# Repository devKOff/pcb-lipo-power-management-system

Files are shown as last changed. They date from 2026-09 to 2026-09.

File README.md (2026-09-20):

<div align="center">

# Project 2 — Power Management System

**A compact, integrated PCB for Li-Po battery charging, protection, and switch-selectable 5 V / 12 V output.**

Combines a TP4056 Li-Po charging stage, DW01A/FS8205A battery protection, and an MT3608 boost
converter on a single two-layer board — designed for portable electronics, IoT nodes,
Arduino-based projects, and lightweight UAV subsystems.






</div>

---

## Table of Contents

- [Overview](#overview)
- [3D Board Renders](#3d-board-renders)
- [Schematic](#schematic)
- [PCB Layer Breakdown](#pcb-layer-breakdown)
- [Bill of Materials & Manufacturing Files](#bill-of-materials--manufacturing-files)
- [Repository Structure](#repository-structure)
- [Getting Started](#getting-started)
- [License](#license)

---

## Overview

| | |
|---|---|
| **Board name** | Project 2 — Power Management System |
| **Function** | Li-Po charging + protection + selectable 5 V/12 V boost output |
| **Charging IC** | TP4056 (USB Type-C input, CC/CV charging) |
| **Protection ICs** | DW01A + FS8205A (overcharge / over-discharge / overcurrent) |
| **Boost converter** | MT3608 (switch-selectable ≈5 V / ≈12 V output) |
| **Layers** | 2-layer PCB |
| **EDA tool** | KiCad v10 |

---

## 3D Board Renders

<div align="center">

<table>
  <tr>
    <td align="center"><strong>Isometric View</strong></td>
    <td align="center"><strong>Top View</strong></td>
    <td align="center"><strong>Bottom View</strong></td>
  </tr>
  <tr>
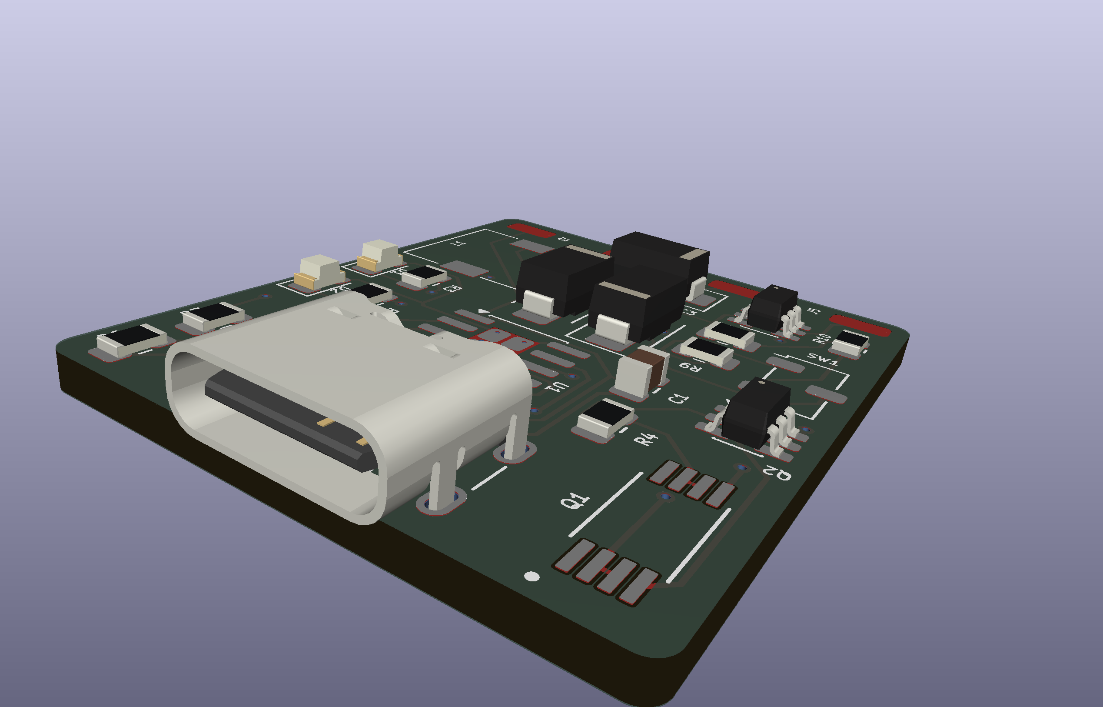
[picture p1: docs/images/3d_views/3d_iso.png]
Isometric 3D render of the PCB
    <td></td>
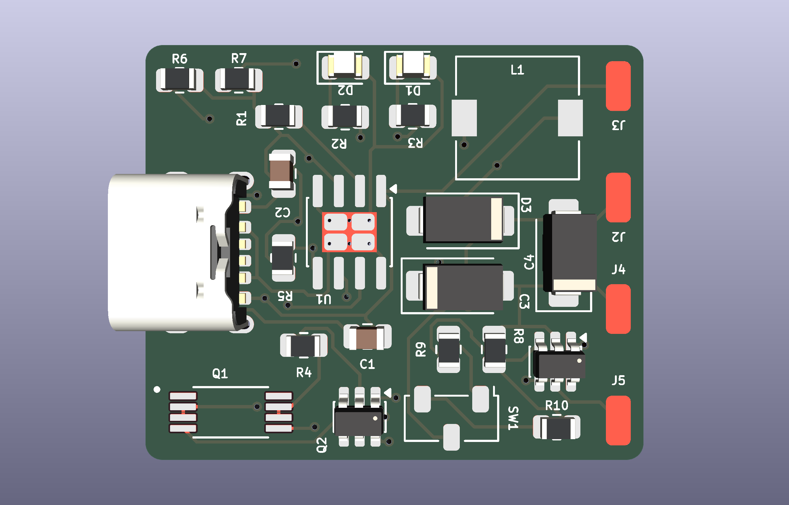
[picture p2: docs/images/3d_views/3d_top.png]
Top 3D render of the PCB
    <td></td>
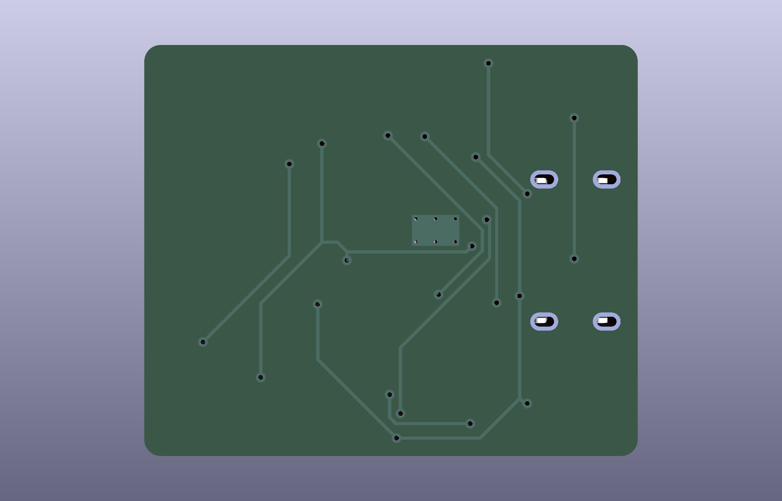
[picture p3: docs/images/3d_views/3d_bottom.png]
Bottom 3D render of the PCB
    <td></td>
  </tr>
</table>

</div>

---

## Schematic

Full schematic of the charging, protection, and boost-conversion circuitry:

<div align="center">
  Project 2 full schematic
</div>

> If the vector render above does not display (GitHub occasionally sandboxes inline SVG),
> open it directly: [`docs/images/schematics/project2.svg`](docs/images/schematics/project2.svg).
> A PNG fallback may also be available at `docs/images/schematics/project2.png`.

---

## PCB Layer Breakdown

### Primary Layers

**Top Copper (F.Cu)** | **Bottom Copper (B.Cu)**
:---:|:---:
Top Copper | Bottom Copper

**Top Silkscreen (F.Silkscreen)** | **Bottom Silkscreen (B.Silkscreen)**
:---:|:---:
Top Silkscreen | Bottom Silkscreen

**Board Outline (Edge.Cuts)**
:---:
Edge Cuts

### Supplementary Layers

<details>
<summary><strong>All-Layers Overlay</strong> (click to expand)</summary>
<br>

All Layers Overlay

</details>

<details>
<summary><strong>Solder Mask Layers — Top (F.Mask) &amp; Bottom (B.Mask)</strong> (click to expand)</summary>
<br>

**Top Solder Mask (F.Mask)** | **Bottom Solder Mask (B.Mask)**
:---:|:---:
Top Solder Mask | Bottom Solder Mask

</details>

---

## Bill of Materials & Manufacturing Files

| Deliverable | Description | Link |
|---|---|---|
| 📋 Bill of Materials | Full component list with references, values, and quantities | [`docs/power_management_system_bom.csv`](docs/power_management_system_bom.csv) |
| 🏭 Gerber Files | Fabrication-ready Gerber package for PCB manufacturing | [`gerbers/`](gerbers/) |
| 🧩 STEP 3D CAD File | Mechanical 3D model for enclosure/assembly integration | [`step/`](step/) |
| 🗂️ KiCad Project | Top-level KiCad project file | [`project2.kicad_pro`](project2.kicad_pro) |
| 🔲 KiCad PCB Layout | Editable PCB layout file | [`project2.kicad_pcb`](project2.kicad_pcb) |
| ⚡ KiCad Schematic | Editable schematic source file | [`project2.kicad_sch`](project2.kicad_sch) |

> **Note:** If the BOM is provided as a spreadsheet instead of CSV, use
> [`docs/power_management_system_bom.xlsx`](docs/power_management_system_bom.xlsx).

---

## Repository Structure

```text
pcb-lipo-power-management-system/
├── docs/
│   ├── images/
│   │   ├── 3d_views/
│   │   │   ├── 3d_top.png
│   │   │   ├── 3d_iso.png
│   │   │   └── 3d_bottom.png
│   │   ├── schematics/
│   │   │   └── project2.svg
│   │   └── pcb_layers/
│   │       ├── pcb_All_layers.svg
│   │       ├── project2-F_Cu.svg
│   │       ├── project2-B_Cu.svg
│   │       ├── project2-F_Silkscreen.svg
│   │       ├── project2-B_Silkscreen.svg
│   │       ├── project2-F_Mask.svg
│   │       ├── project2-B_Mask.svg
│   │       └── project2-Edge_Cuts.svg
│   └── power_management_system_bom.csv
├── gerbers/
│   └── (fabrication Gerber + drill files)
├── step/
│   └── (STEP 3D CAD export)
├── assets/
│   └── datasheets/
│       └── (component datasheets: TP4056, MT3608, DW01A, FS8205A, etc.)
├── .history/
│   └── (local edit history / backups, excluded from releases)
├── .gitignore
├── DRC.rpt
├── report.txt
├── project2.kicad_pro
├── project2.kicad_pcb
├── project2.kicad_prl
├── project2.kicad_sch
├── LICENSE
└── README.md
```

> **Note:** `.history/`, `DRC.rpt`, `report.txt`, and `temp-freerouting.dsn` are local
> KiCad/tooling artifacts. Consider adding them to `.gitignore` if they don't need to be
> version-controlled — they're listed here only for completeness.

---

## Getting Started

1. **Clone the repository**
   ```bash
   git clone https://github.com/devKOff/pcb-lipo-power-management-system.git
   cd pcb-lipo-power-management-system
   ```
2. **Open in KiCad v10**
   Open [`project2.kicad_pro`](project2.kicad_pro) in KiCad to view or edit the schematic and PCB layout.
3. **Manufacture the board**
   Send the contents of [`gerbers/`](gerbers/) directly to your PCB fabricator, and reference
   [`docs/power_management_system_bom.csv`](docs/power_management_system_bom.csv) for assembly.
4. **Mechanical integration**
   Import the STEP file from [`step/`](step/) into your CAD tool of choice for enclosure or
   assembly design.

---

## License

This project is released under the terms of the [MIT License](LICENSE). Hardware design files
are shared in the spirit of open source hardware — see the OSHW badge above.

> **Note:** No `LICENSE` file currently exists in this repository. Add one (e.g. via GitHub's
> *Add file → Create new file → LICENSE* flow, which offers an MIT template) so the badge and
> link above resolve correctly — see Step 6 in the upload guide below.

<div align="center">

*Maintained as part of the Project 2 — Power Management System hardware design effort.*

</div>

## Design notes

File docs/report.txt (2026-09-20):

Plotted to 'E:\GIT\PCB\project1\project2\docs\project2.ps'.
Info: Done.

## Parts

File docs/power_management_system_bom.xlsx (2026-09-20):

Bill of Materials (BOM) — Power Management System
Project: Integrated PCB Li-Po Charger & Selectable 5V/12V Boost Module | Sheet: 1/1
Item # | Ref Des | Qty | Value / Part | Category / Function | KiCad Symbol Library | Footprint / Package | Part Number / LCSC Ref | Description
Active Integrated Circuits & Semiconductors
1 | U1 | 1 | TP4056-42-ESOP8 | Power Management IC | Power_Management | Package_SO:SOP-8-PP_3.9x4.9mm_P1.27mm | TP4056 / C16581 | 1A Standalone Linear Li-Ion Battery Charger
2 | U2 | 1 | MT3608 | DC-DC Boost Converter | Power_Switching | Package_TO_SOT_SMD:SOT-23-6 | MT3608 / C84817 | 1.2MHz, 2A High-Efficiency Step-Up Converter
3 | U3 | 1 | DW01A | Battery Protection IC | Battery_Management | Package_TO_SOT_SMD:SOT-23-6 | DW01A / C14211 | One-Cell Li-Ion/Li-Po Battery Protection Controller
4 | Q1 | 1 | FS8205A | Protection MOSFET | Transistor_FET | Package_SO:TSSOP-8_4.4x3mm_P0.65mm | FS8205A / C16130 | Dual N-Channel Common-Drain MOSFET Switch
5 | D3 | 1 | SS34 | Schottky Diode | Diode | Diode_SMD:D_SMA | SS34 / C1591 | 3A / 40V Surface Mount Schottky Barrier Diode
6 | D1, D2 | 2 | LED (Red/Green) | Status Indicators | Device | LED_SMD:LED_0805_2012Metric | Generic 0805 LED | Surface Mount Status Indicators (CHRG / STDBY)
Resistors (SMD 0805)
7 | R1 | 1 | 1.2kΩ | Resistor | Device | Resistor_SMD:R_0805_2012Metric | 0805W8F1201T5E | Sets TP4056 charge current to 1A (PROG)
8 | R2, R3 | 2 | 1kΩ | Resistor | Device | Resistor_SMD:R_0805_2012Metric | 0805W8F1001T5E | LED Current Limiting Resistors
9 | R4 | 1 | 1kΩ | Resistor | Device | Resistor_SMD:R_0805_2012Metric | 0805W8F1001T5E | DW01A Overcurrent Current-Sense Resistor
10 | R5 | 1 | 100Ω | Resistor | Device | Resistor_SMD:R_0805_2012Metric | 0805W8F1000T5E | DW01A VCC Filtering Resistor
11 | R6, R7 | 2 | 5.1kΩ | Resistor | Device | Resistor_SMD:R_0805_2012Metric | 0805W8F5101T5E | USB Type-C CC1/CC2 Pull-down Resistors
12 | R8 | 1 | 2.2kΩ | Resistor | Device | Resistor_SMD:R_0805_2012Metric | 0805W8F2201T5E | MT3608 Feedback Divider Ground Resistor
13 | R9 | 1 | 42kΩ | Resistor | Device | Resistor_SMD:R_0805_2012Metric | 0805W8F4202T5E | MT3608 Feedback Resistor (Selects ~12V Output)
14 | R10 | 1 | 16kΩ | Resistor | Device | Resistor_SMD:R_0805_2012Metric | 0805W8F1602T5E | MT3608 Feedback Resistor (Selects ~5V Output)
Capacitors & Power Passives
15 | C1 | 1 | 10uF | Ceramic Capacitor | Device | Capacitor_SMD:C_0805_2012Metric | CL21A106KOQNNNE | TP4056 Input/Output Decoupling Capacitor
16 | C2 | 1 | 100nF | Ceramic Capacitor | Device | Capacitor_SMD:C_0603_1608Metric | CL10B104KO8NNNC | DW01A VCC Power Decoupling Capacitor
17 | C3, C4 | 2 | 10uF | Ceramic Capacitor | Device | Capacitor_SMD:C_0805_2012Metric | CL21A106KOQNNNE | MT3608 Input & Output Filter Capacitors
18 | L1 | 1 | 22uH | Power Inductor | Device | Inductor_SMD:L_7.3x7.3_H4.5 | CDRH74T-220MC / C16822 | 22µH Shielded Power Inductor (Boost Converter)
Connectors & Switches
19 | J1 | 1 | USB_C_6P | USB Receptacle | Connector | Connector_USB:USB_C_Receptacle_6P | TYPE-C-31-M-12 / C165948 | USB Type-C 6-Pin Power Input Jack
20 | SW1 | 1 | SW_SPDT | Slide Switch | Switch | Button_Switch_SMD:SW_SPDT_PCM12 | CAS-120A1 / SK-12D07 | SPDT Switch for 5V / 12V Voltage Rail Selection
21 | J2, J3 | 2 | 1-Pin Header | Output Terminal | Connector | Connector_PinHeader_2.54mm:1x01 | Generic 2.54mm Header | System Output Pins (OUT+, OUT-)
22 | J4, J5 | 2 | 1-Pin Header | Battery Terminal | Connector | Connector_PinHeader_2.54mm:1x01 | Generic 2.54mm Header | Li-Po Battery Connector Pins (BAT+, BAT-)
Total Components:

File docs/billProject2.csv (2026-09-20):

Reference | Qty | Value | DNP | Exclude from BOM | Exclude from Board | Exclude from Simulation | Exclude from Position Files | Footprint | Datasheet
C1 | 1 | 10uF |  |  |  |  | ${EXCLUDE_FROM_POS_FILES} | Capacitor_SMD:C_0805_2012Metric
C2 | 1 | 100nF |  |  |  |  | ${EXCLUDE_FROM_POS_FILES} | Capacitor_SMD:C_0805_2012Metric
C3,C4 | 2 | C |  |  |  |  | ${EXCLUDE_FROM_POS_FILES} | Diode_SMD:D_SMA
D1,D2 | 2 | LED |  |  |  |  | ${EXCLUDE_FROM_POS_FILES} | LED_SMD:LED_0805_2012Metric
D3 | 1 | SS34 |  |  |  |  | ${EXCLUDE_FROM_POS_FILES} | Diode_SMD:D_SMA | https://www.vishay.com/docs/88751/ss32.pdf
J1 | 1 | USB_C_Receptacle_PowerOnly_6P |  |  |  |  | ${EXCLUDE_FROM_POS_FILES} | Connector_USB:USB_C_Receptacle_GCT_USB4125-xx-x_6P_TopMnt_Horizontal | https://www.usb.org/sites/default/files/documents/usb_type-c.zip
J2,J3,J4,J5 | 4 | Conn_01x01_Socket |  |  |  |  | ${EXCLUDE_FROM_POS_FILES} | Connector_Wire:SolderWirePad_1x01_SMD_1.5x3mm
L1 | 1 | 22uH |  |  |  |  | ${EXCLUDE_FROM_POS_FILES} | Inductor_SMD:L_7.3x7.3_H4.5
Q1 | 1 | FS8205A |  |  |  |  | ${EXCLUDE_FROM_POS_FILES} | FS8205A:SOP65P640X120-8N
Q2 | 1 | DW01A |  |  |  |  | ${EXCLUDE_FROM_POS_FILES} | Package_TO_SOT_SMD:SOT-23-6
R1 | 1 | 1.2k |  |  |  |  | ${EXCLUDE_FROM_POS_FILES} | Resistor_SMD:R_0805_2012Metric
R2,R3,R4 | 3 | 1k |  |  |  |  | ${EXCLUDE_FROM_POS_FILES} | Resistor_SMD:R_0805_2012Metric
R5 | 1 | 100 |  |  |  |  | ${EXCLUDE_FROM_POS_FILES} | Resistor_SMD:R_0805_2012Metric
R6,R7 | 2 | 5.1k |  |  |  |  | ${EXCLUDE_FROM_POS_FILES} | Resistor_SMD:R_0805_2012Metric
R8 | 1 | 2.2k |  |  |  |  | ${EXCLUDE_FROM_POS_FILES} | Resistor_SMD:R_0805_2012Metric
R9 | 1 | 42k |  |  |  |  | ${EXCLUDE_FROM_POS_FILES} | Resistor_SMD:R_0805_2012Metric
R10 | 1 | 16k |  |  |  |  | ${EXCLUDE_FROM_POS_FILES} | Resistor_SMD:R_0805_2012Metric
SW1 | 1 | SW_Nidec_CAS-120A1 |  |  |  |  | ${EXCLUDE_FROM_POS_FILES} | Button_Switch_SMD:Nidec_Copal_CAS-120A | https://www.nidec-components.com/e/catalog/switch/cas.pdf
U1 | 1 | TP4056-42-ESOP8 |  |  |  |  | ${EXCLUDE_FROM_POS_FILES} | Package_SO:SOIC-8-1EP_3.9x4.9mm_P1.27mm_EP2.41x3.3mm_ThermalVias | https://www.lcsc.com/datasheet/lcsc_datasheet_2410121619_TOPPOWER-Nanjing-Extension-Microelectronics-TP4056-42-ESOP8_C16581.pdf
U2 | 1 | MT3608 |  |  |  |  | ${EXCLUDE_FROM_POS_FILES} | Package_TO_SOT_SMD:SOT-23-6 | https://www.olimex.com/Products/Breadboarding/BB-PWR-3608/resources/MT3608.pdf

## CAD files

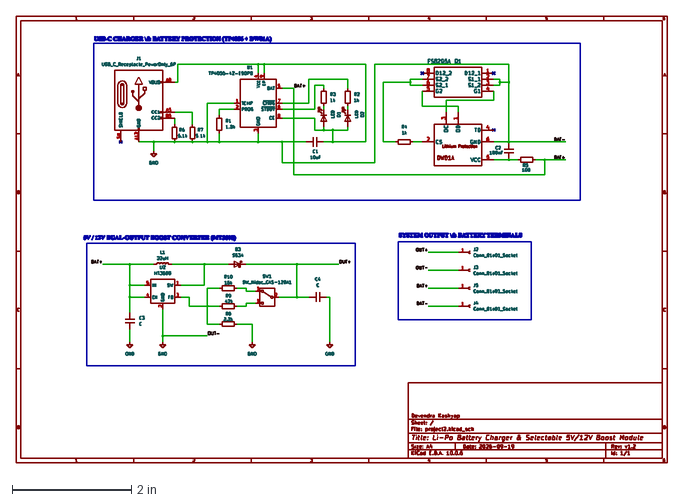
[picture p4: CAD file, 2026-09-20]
docs/project2.dxf
10.9 x 7.48 in

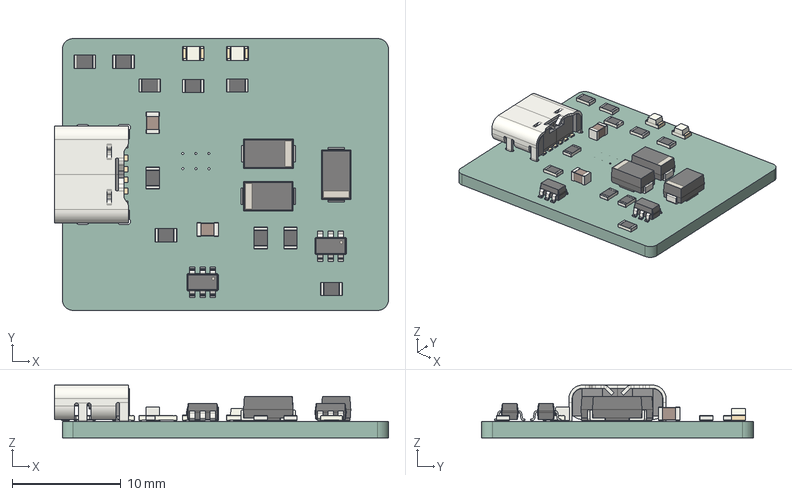
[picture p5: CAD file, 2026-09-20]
step/project2.step
30.7 x 25.0 x 4.85 mm
R_0805_2012Metric x 10
D_SMA x 3
C_0805_2012Metric x 2
SOT-23-6 x 2
LED_0805_2012Metric x 2
USB_C_Receptacle_GCT_USB4125-xx-x_6P_TopMnt_Horizontal
pro2E28_PCB

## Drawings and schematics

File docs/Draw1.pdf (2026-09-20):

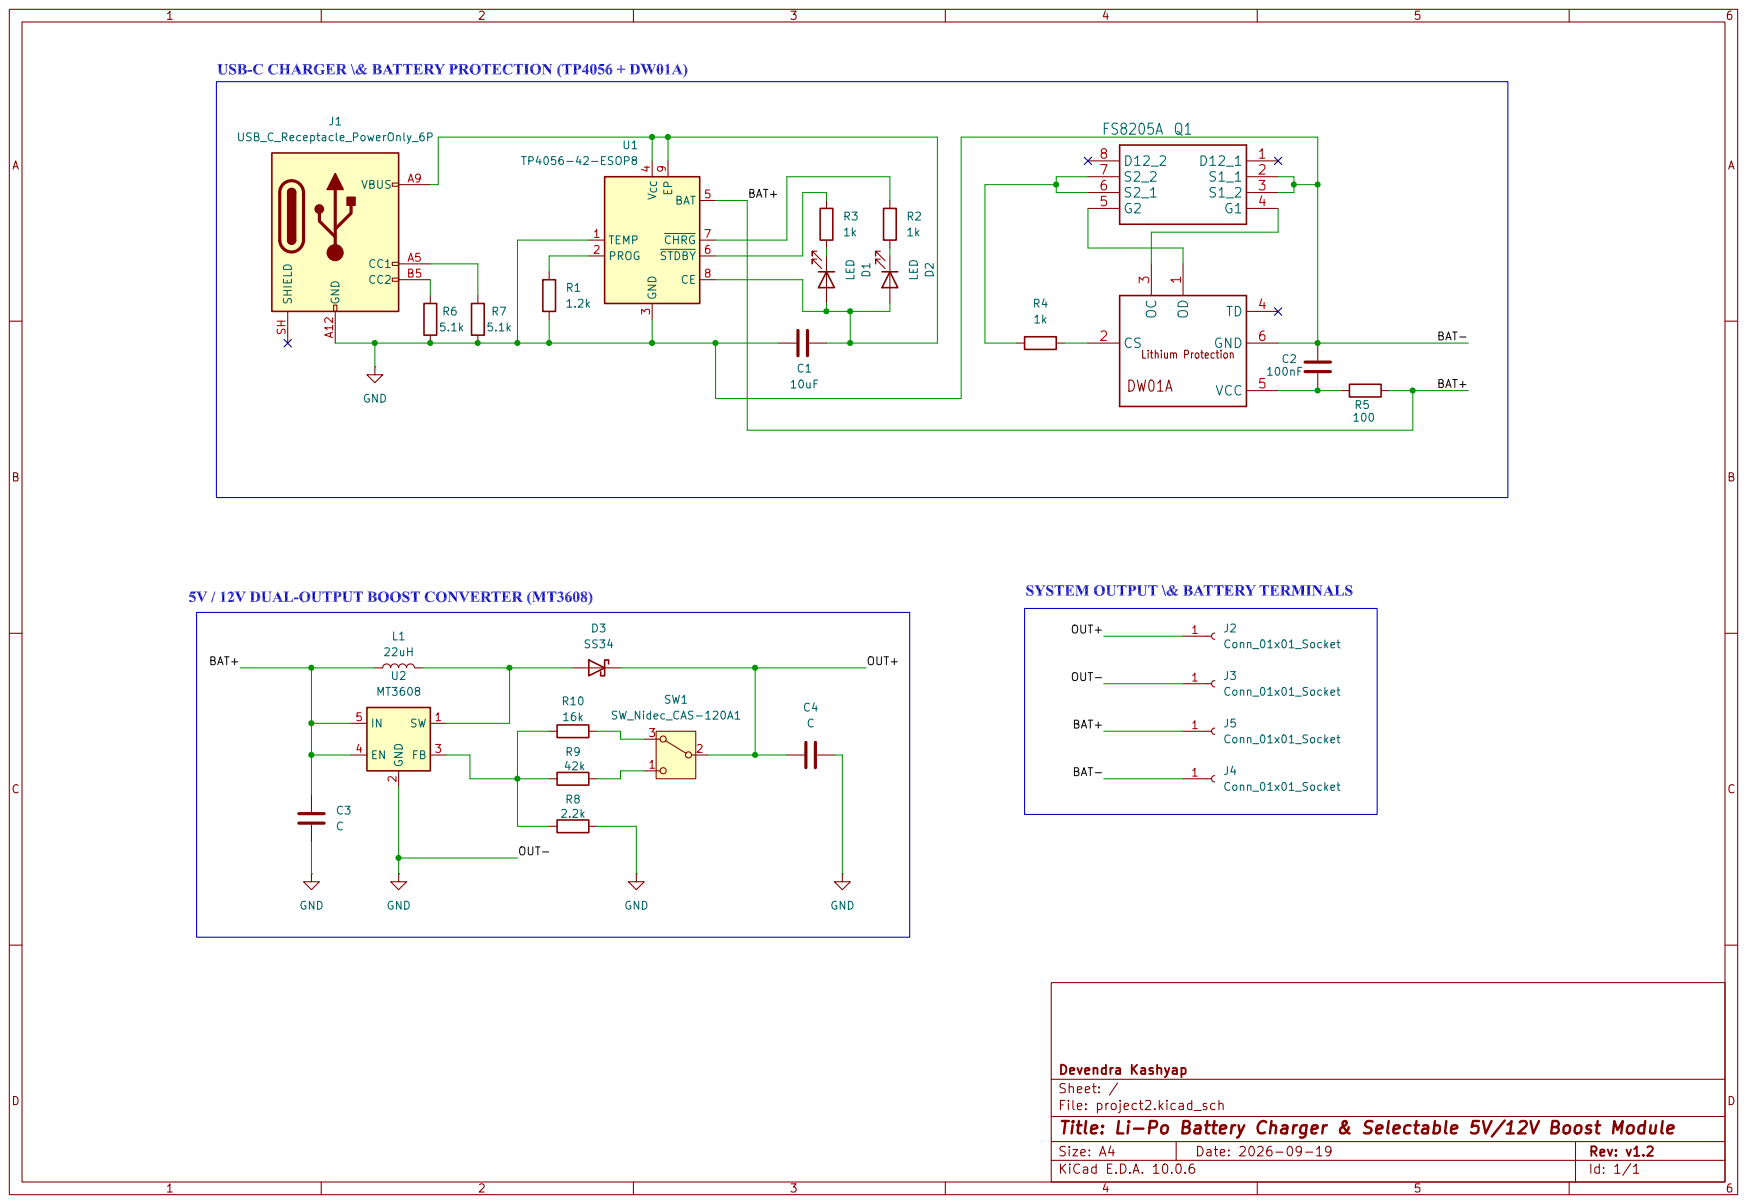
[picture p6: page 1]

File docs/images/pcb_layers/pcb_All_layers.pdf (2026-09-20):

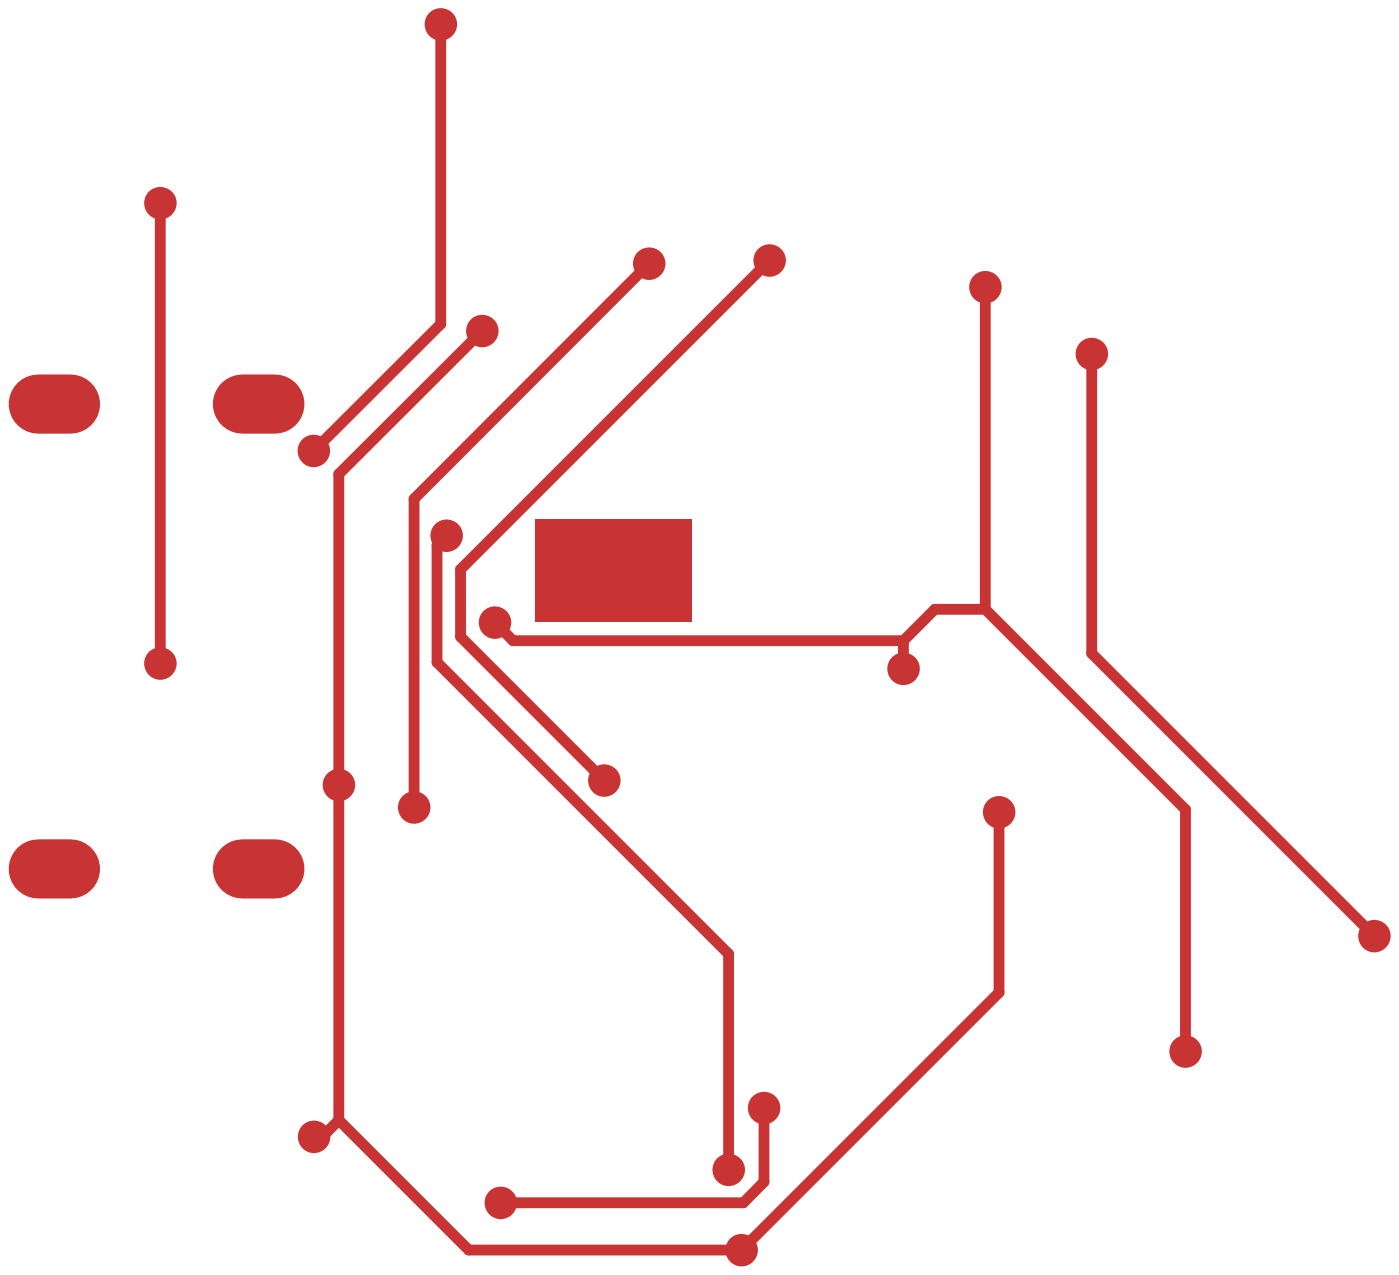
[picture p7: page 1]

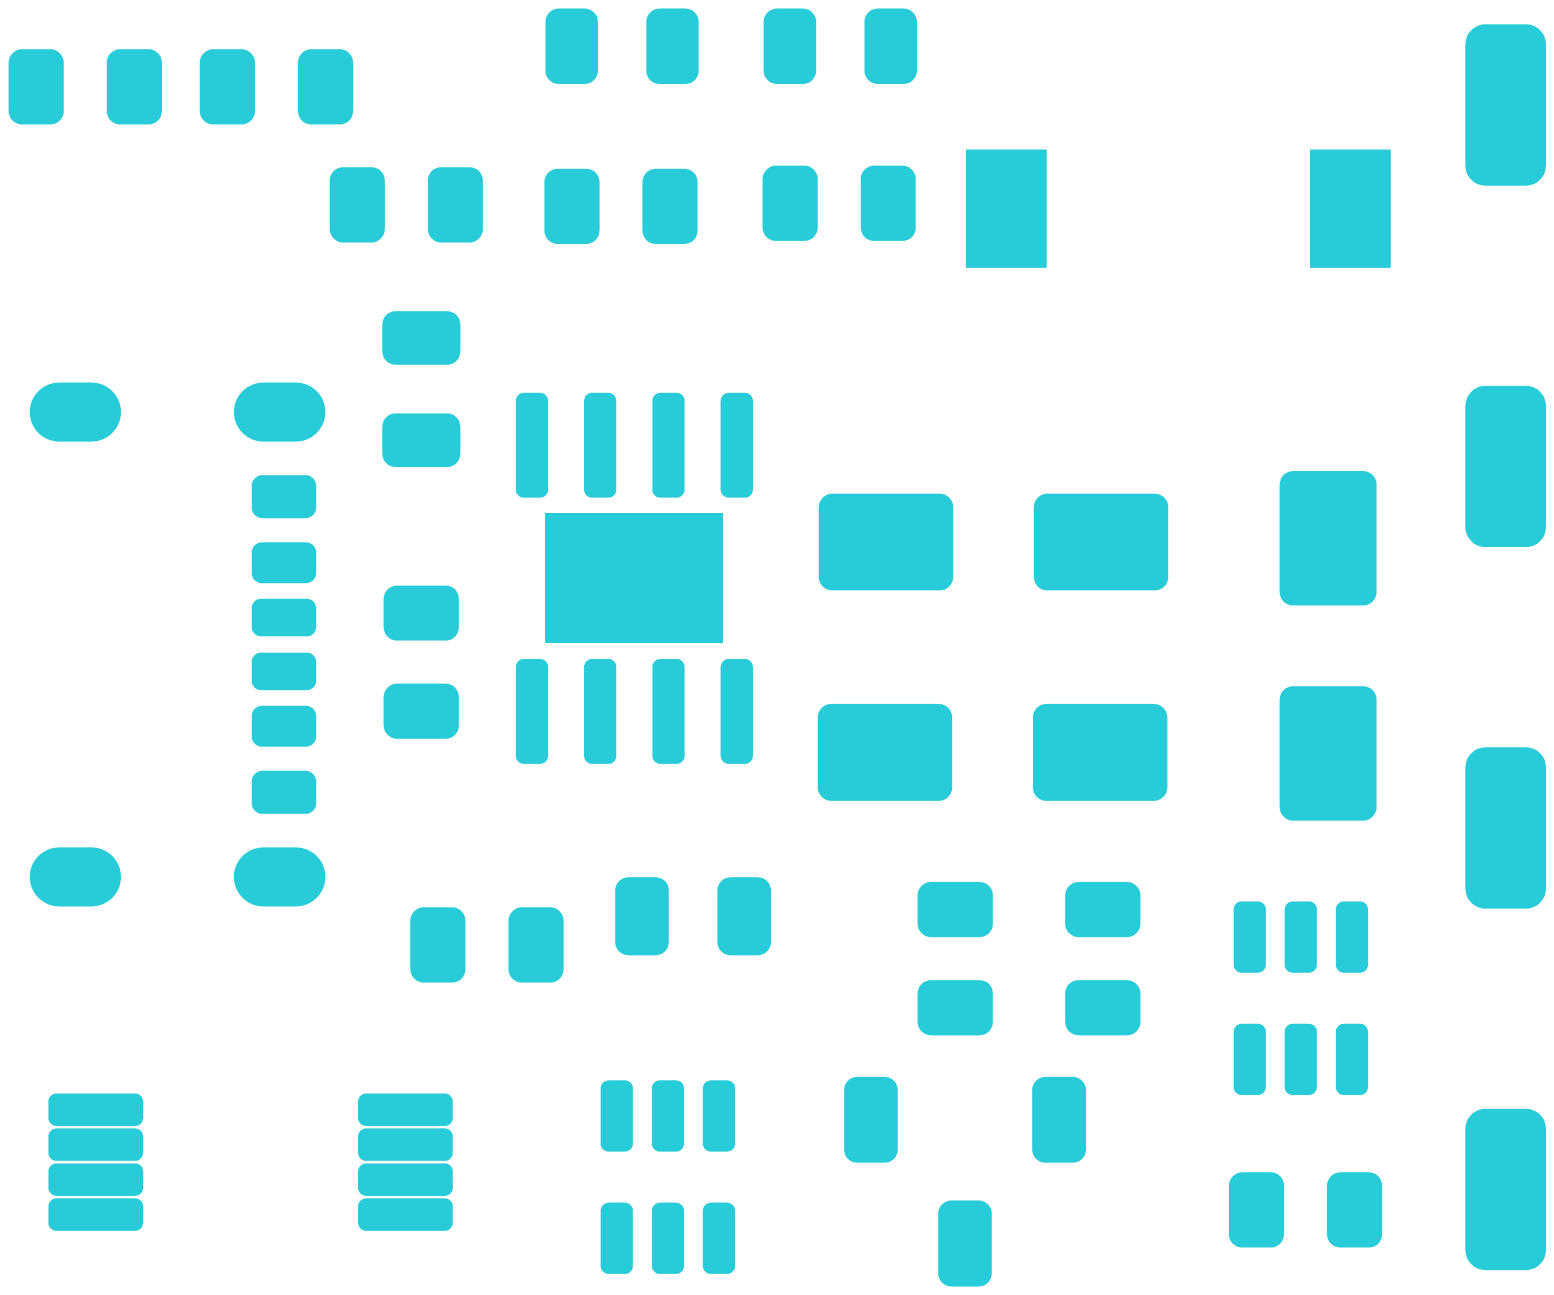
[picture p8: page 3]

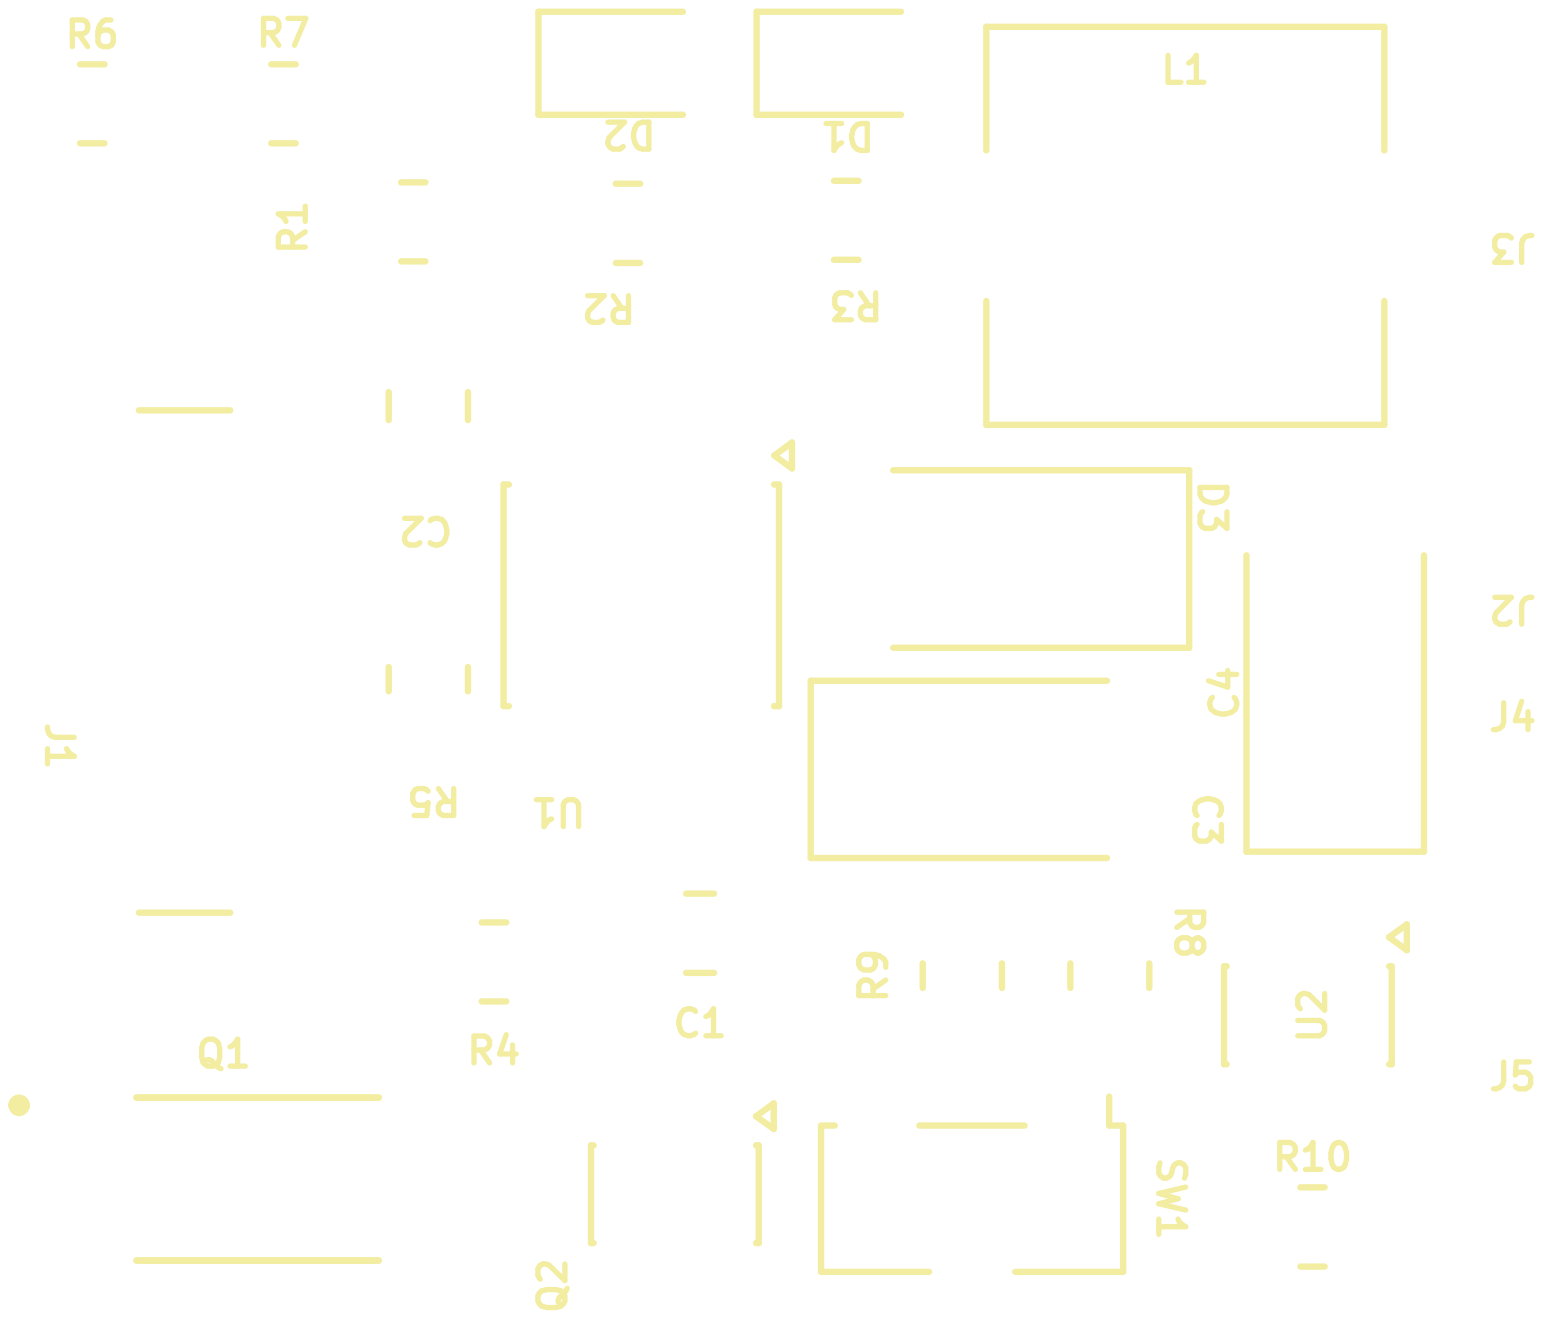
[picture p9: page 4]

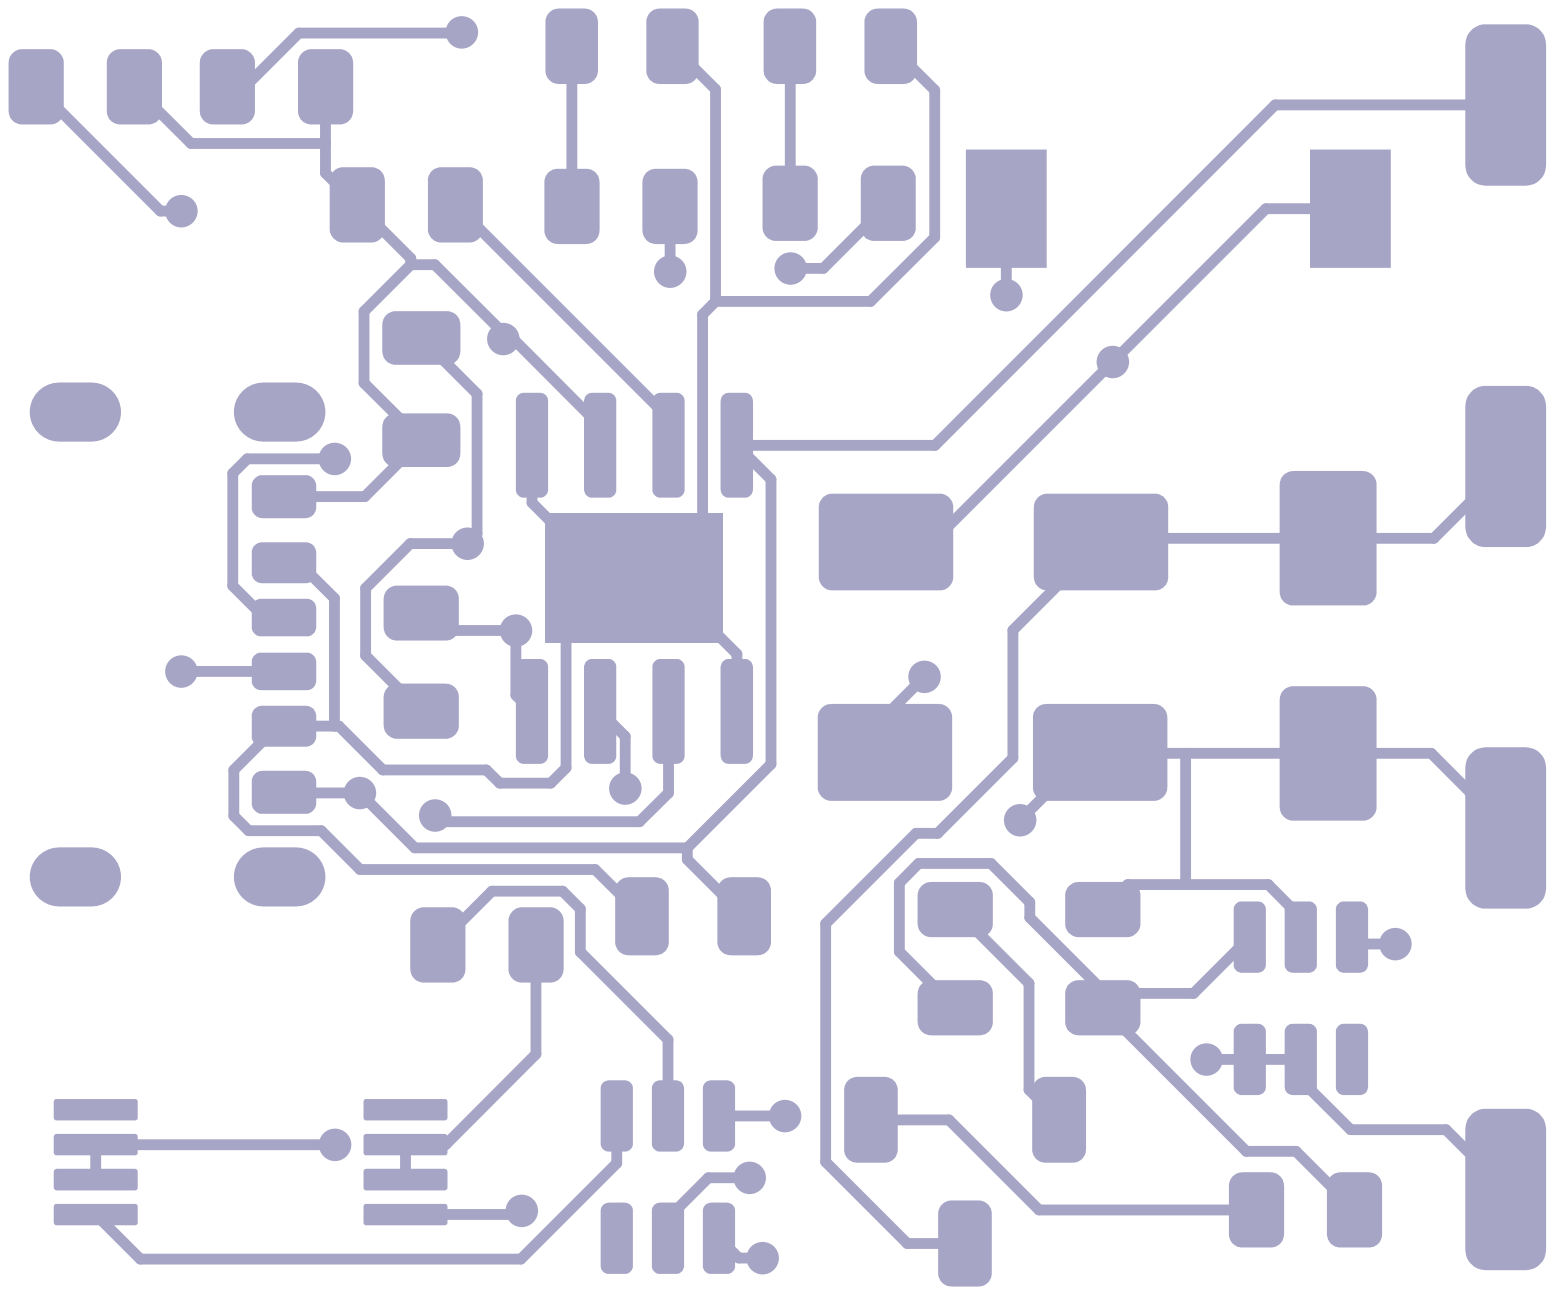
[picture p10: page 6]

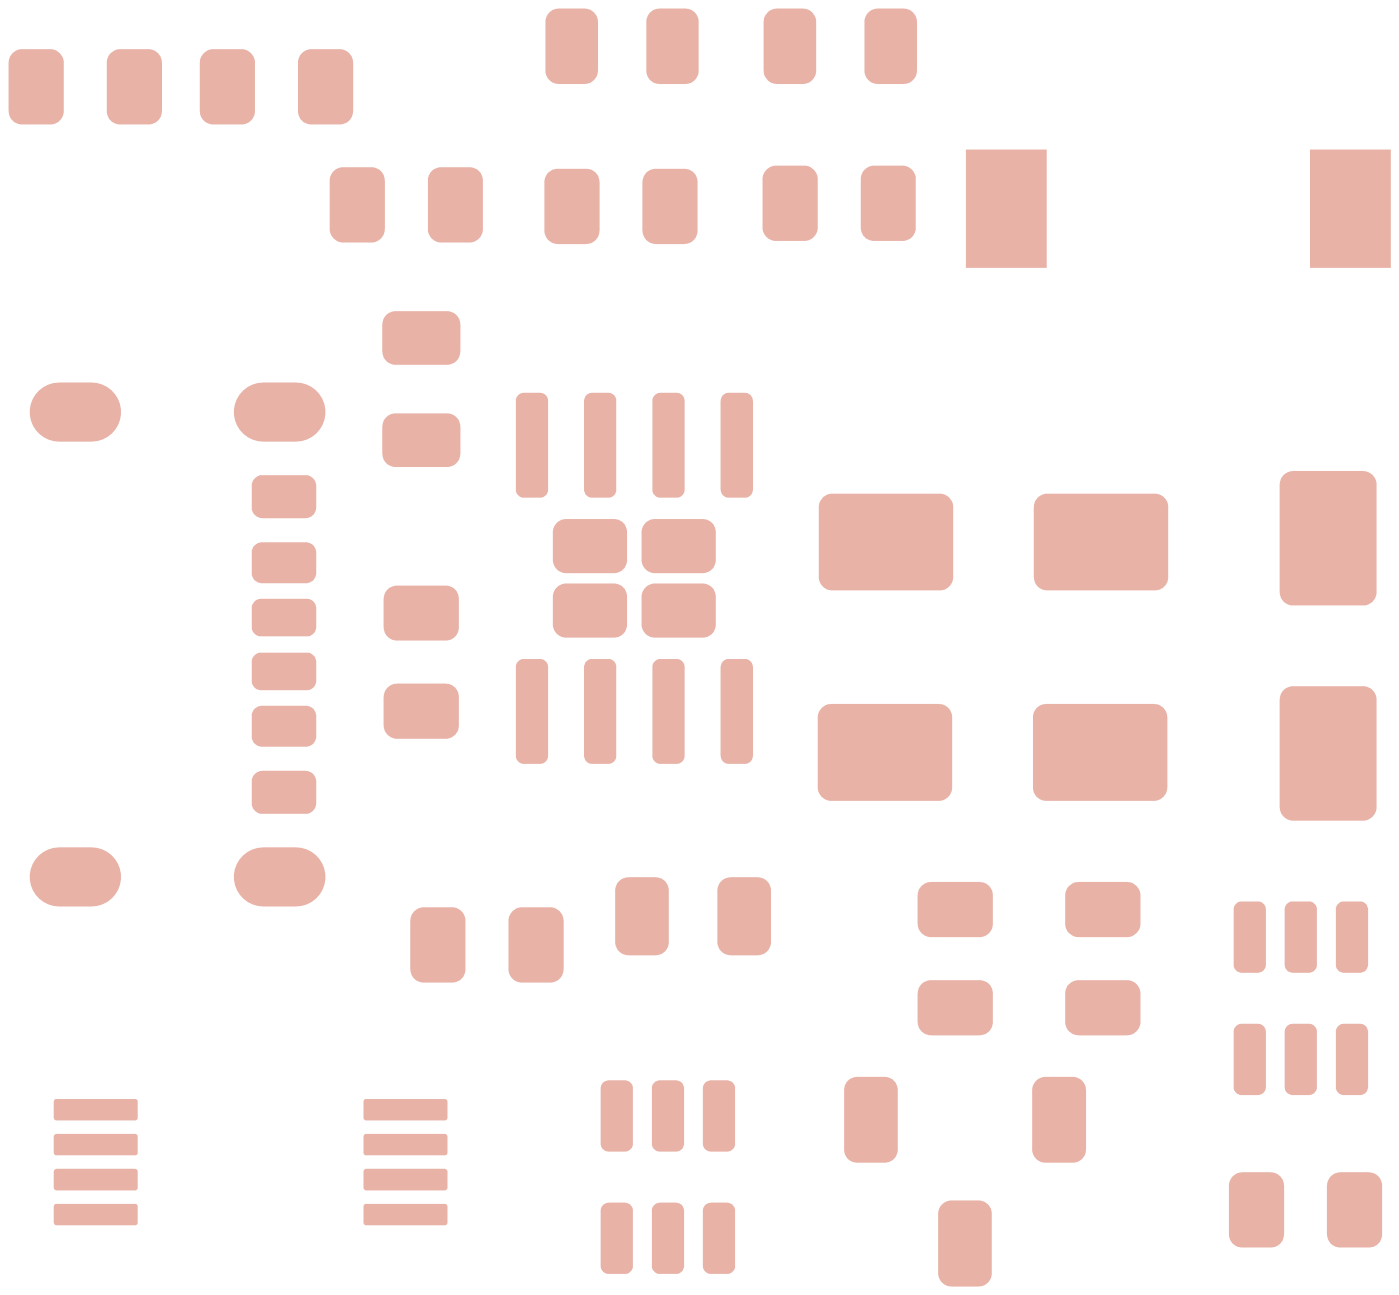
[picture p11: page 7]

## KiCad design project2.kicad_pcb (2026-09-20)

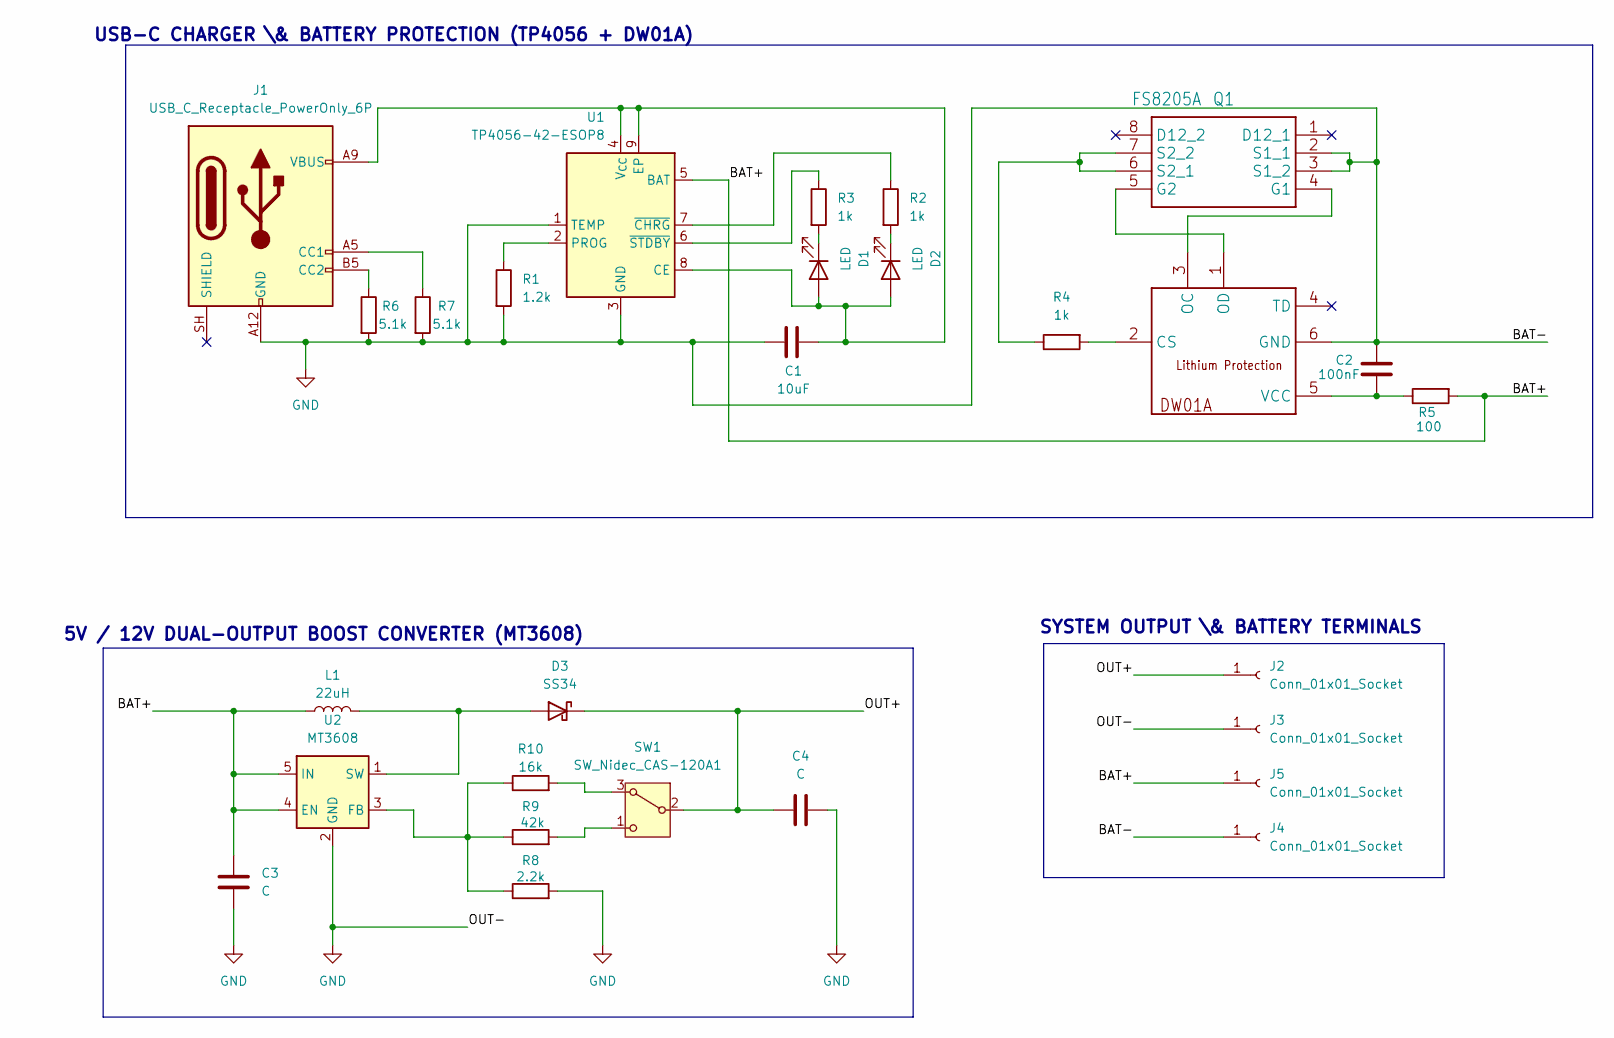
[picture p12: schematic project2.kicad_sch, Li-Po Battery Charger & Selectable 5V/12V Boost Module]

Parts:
C1: 10uF; C_0805_2012Metric
C2: 100nF; C_0805_2012Metric
C3, C4: C; D_SMA
D1, D2: LED; LED_0805_2012Metric
D3: SS34; D_SMA
J1: USB_C_Receptacle_PowerOnly_6P; USB_C_Receptacle_GCT_USB4125-xx-x_6P_TopMnt_Horizontal
J2, J3, J4, J5: Conn_01x01_Socket; SolderWirePad_1x01_SMD_1.5x3mm
L1: 22uH; L_7.3x7.3_H4.5
Q1: FS8205A; SOP65P640X120-8N; Manufacturer_Part_Number FS8205A
Q2: DW01A; SOT-23-6
R1: 1.2k; R_0805_2012Metric
R2, R3, R4: 1k; R_0805_2012Metric
R5: 100; R_0805_2012Metric
R6, R7: 5.1k; R_0805_2012Metric
R8: 2.2k; R_0805_2012Metric
R9: 42k; R_0805_2012Metric
R10: 16k; R_0805_2012Metric
SW1: SW_Nidec_CAS-120A1; Nidec_Copal_CAS-120A
U1: TP4056-42-ESOP8; SOIC-8-1EP_3.9x4.9mm_P1.27mm_EP2.41x3.3mm_ThermalVias
U2: MT3608; SOT-23-6

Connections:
/BAT+: C3.1, J5.1 (Pin_1_1), L1.1, R5.2, U1.5 (BAT), U2.4 (EN), U2.5 (IN)
/OUT+: C4.2, D3.1 (K), J2.1 (Pin_1_1), SW1.2 (B)
GND: C1.1, C2.1, C3.2, C4.1, J1.A12 (GND), J1.B12 (GND), J3.1 (Pin_1_1), J4.1 (Pin_1_1), Q1.2 (S1_1), Q1.3 (S1_2), Q2.6 (GND), R1.2, R6.2, R7.2, R8.2, U1.1 (TEMP), U1.3 (GND), U2.2 (GND)
unnamed: C1.2, D1.2 (A), D2.2 (A), J1.A9 (VBUS), J1.B9 (VBUS), U1.4 (V_{CC}), U1.8 (CE), U1.9 (EP)
unnamed: D1.1 (K), R3.2
unnamed: D2.1 (K), R2.2
unnamed: D3.2 (A), L1.2, U2.1 (SW)
unnamed: J1.A5 (CC1), R7.1
unnamed: J1.B5 (CC2), R6.1
unnamed: Q1.4 (G1), Q2.3 (OC)
unnamed: Q1.5 (G2), Q2.1 (OD)
unnamed: Q1.6 (S2_1), Q1.7 (S2_2), R4.1
unnamed: Q2.2 (CS), R4.2
unnamed: C2.2, Q2.5 (VCC), R5.1
unnamed: R10.2, SW1.3 (A)
unnamed: R9.2, SW1.1 (C)
unnamed: R1.1, U1.2 (PROG)
unnamed: R2.1, U1.7 (~CHRG)
unnamed: R3.1, U1.6 (~STDBY)
unnamed: R8.1, R9.1, R10.1, U2.3 (FB)

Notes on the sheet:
USB-C CHARGER \& BATTERY PROTECTION (TP4056 + DW01A)
5V / 12V DUAL-OUTPUT BOOST CONVERTER (MT3608)
SYSTEM OUTPUT \& BATTERY TERMINALS

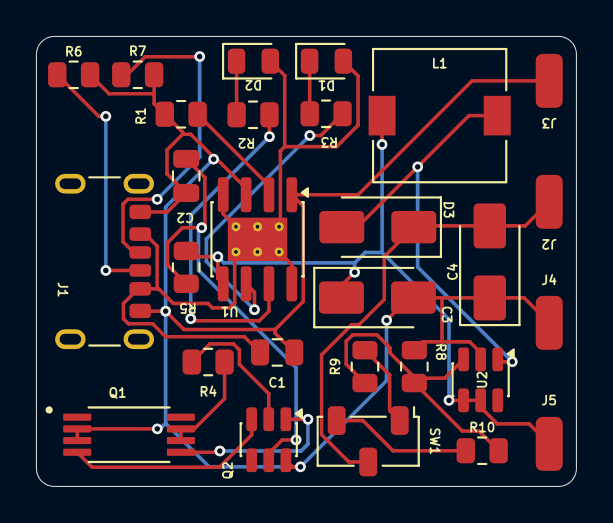
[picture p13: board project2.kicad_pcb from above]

Board: 2 copper layers, 30.0 x 25.0 mm, 28 parts (0 on the bottom side), 20 nets.

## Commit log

2026-09-19 Initial commit: Complete TP4056 + DW01A KiCad schematic and footprint assignments
    [project2.kicad_pcb, project2.kicad_sch]
2026-09-19 docs: Set up repository structure with images, datasheets, and BOM
2026-09-19 MT3608 added
    [project2.kicad_pcb, project2.kicad_sch]
2026-09-20 PCB created
    [billProject2.csv, power_management_system_bom.xlsx, project2.dxf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]
2026-09-20 deterent changes
    [project2-B_Cu.gbr, project2-B_Mask.gbr, project2-B_Paste.gbr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]
2026-09-20 Project Compleated v1.2
    [project2.kicad_pcb]
2026-09-20 PROJECT COMPLEATED
    [project2.kicad_pcb]

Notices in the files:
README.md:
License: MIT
